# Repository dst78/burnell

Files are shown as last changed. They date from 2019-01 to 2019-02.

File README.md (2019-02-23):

# Burnell :: Clock and Clock Divider

## Abstract
This is a combined clock generator and clock divider module based on an Arduino Nano.

## Clock features
- Clock speed adjustable via potentiometer between 10 and 300 BPM.
- Gate length adjustable via potentiometer and gate / trigger toggle switch.
- Switches for start/stop and reset.
- Reset trigger output.
- Clock outputs for beat, bar, 8ths, 16ths and 32ths.

## Function of the gate length control
The gate length potentiometer varies the length of the high-state of an output between 5% and 95% of its interval.

This makes the module useful for both triggers and to control envelopes and similar modules which require long gates.

When the gate / trigger switch is in the trigger position then the high-state length of all outputs equals that of the 32ths output instead. You can still control the 32ths output gate length with the gate length potentiometer as before.

## Clock divider features
The clock divider section of the module has an external clock input so you can use it to divide an external pulse just as well as the internal clock. By default the clock divider is normalled to the bar output of the clock section.

The divider can be switched between three modes, which changes the outputs to:
- power of two: 2, 4, 8, 16, 32, 64, 128, 256
- primes      : 2, 3, 5, 7, 11, 13, 17,  19
- fibonacci   : 2, 3, 5, 8, 13, 21, 34,  55

The gate / trigger toggle switch of the clock section affects the gate length of the clock divider in the same way that it affects the clock outputs.

## Technical Specifications
The module is 12 HE wide.

Power consumption:
- 5V: 20mA
- +12V: 25mA
- -12V: 25mA

## Required Arduino Libraries
Burnell requires the following libraries:

- [PinChangeInterrupt](https://github.com/NicoHood/PinChangeInterrupt) by [Nico Hood](https://github.com/NicoHood) (version 1.2.6 confirmed to work) - also available directly through the library manager in the Arduino IDE
- [RBD_MicroTimer](https://github.com/dst78/arduinolib_RBD_MicroTimer) by [myself](https://github.com/dst78/) (version 1.4.1 confirmed to work).

**Do NOT use the RBD_Timer library found in the library manager**! It operates on milliseconds rather than microseconds and will not provide the resolution required for smooth clocks at higher BPM settings. Use my fork linked above instead and install it manually.

See the [Arduino Guide](https://www.arduino.cc/en/guide/libraries#toc5) on how to install a library manually if you're not sure how to do that.

## What's in the name
The module was named after [Jocelyn Bell Burnell](https://en.wikipedia.org/wiki/Jocelyn_Bell_Burnell), who together with Antony Hewish first discovered Pulsars when she was a postgraduate student. Antony Hewish, her supervisor, was awarded the Nobel price in Physics for the discovery. Burnell herself was omitted.

Pulsars are highly magnetized rotating neutron stars which emit beams of electromagnetic radiation. The beam can only observed when their beam is directed at earth. The so generated pulses are highly precise.

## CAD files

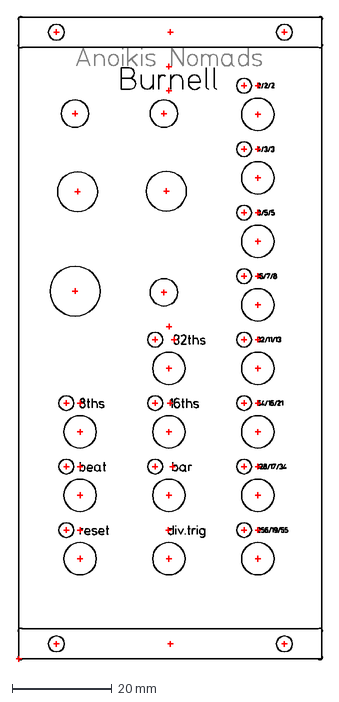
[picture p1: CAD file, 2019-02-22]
eurorack_panel/Burnell.dxf
61.4 x 129.1 mm

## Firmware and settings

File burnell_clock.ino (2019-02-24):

/**
 * Anoikis Nomads :: Burnell
 * Eurorack clock and clock divider module
 * 
 * All information on Burnell is on github: https://github.com/dst78/burnell
 * 
 * Released under Creative Commons Attribution-ShareAlike 3.0 Unported
 * https://creativecommons.org/licenses/by-sa/3.0/deed.de 
 * 
 * Pins and settings below are for an Arduino Nano.
 */
#include <PinChangeInterrupt.h>
#include <PinChangeInterruptBoards.h>
#include <PinChangeInterruptPins.h>
#include <PinChangeInterruptSettings.h>
#include <RBD_MicroTimer.h>

RBD::MicroTimer clockTimer;
RBD::MicroTimer divTimer;

//---- configure pins 
// input pins w/ interrupt
#define DIV_IN            2
#define RESET_IN          3
// digital output pins
#define SHIFTREG_SER      4
#define SHIFTREG_RCLK     5
#define SHIFTREG_SRCLK    6
#define RST_OUT           7
#define RST_LED           A4
// digital input pins
#define GATEMODE_IN       8
#define STARTSTOP_IN      9
// analog input pins
#define SPEED_IN         A2
#define GATELEN_IN       A1
#define DIVMODE_IN       A0


// program constants
#define DIVMODE_CLOCK     0
#define DIVMODE_POW       1
#define DIVMODE_PRIME     2
#define DIVMODE_FIBONACCI 3
#define GATEMODE_VARIABLE true
#define GATEMODE_FIXED    false
#define STARTED           true
#define STOPPED           false
// gate length range in percent
#define GATELEN_MIN       5
#define GATELEN_MAX      95
// clock speed and speed range in BPM
#define CLOCK_SPEED_MIN  10
#define CLOCK_SPEED_MAX 300
#define CLOCK_RESOLUTION 22.0

/**
 * raw array of divisions for clock and clock divider
 */
uint16_t divs[4][8] = {
  {1, 2, 4,  8, 16, 32,  64, 128}, // internal clock
  {2, 4, 8, 16, 32, 64, 128, 256}, // power of two
  {2, 3, 5,  7, 11, 13,  17,  19}, // prime numbers
  {2, 3, 5,  8, 13, 21,  34,  55}, // fibonacci sequence
};
/**
 * hiked up divisions, will be calculated dynamically based on CLOCK_RESOLUTION
 */
uint16_t subDivs[4][8] = {
  {0, 0, 0, 0, 0, 0, 0, 0},
  {0, 0, 0, 0, 0, 0, 0, 0},
  {0, 0, 0, 0, 0, 0, 0, 0},
  {0, 0, 0, 0, 0, 0, 0, 0}
};
/**
 * least common multiples for all steps in all division modes.
 * used to modulo the clock counters in a way that they never
 * overflow at a position where any of the digits skip a beat.
 */
uint32_t lcms[4] = {128, 256, 9699690, 2042040};

/**
 * interval length of the clock timer in microseconds
 */
double clkSpeed;

/**
 * current gatelength relative to CLOCK_RESOUTION / 100
 */
uint16_t gateLen;
/**
 * adjusted gatelength minimum / maximum in relation to CLOCK_RESOLUTION / 100
 */
uint8_t gateLenMin, gateLenMax;
/**
 * indicates the gate mode, derived from GATEMODE_IN
 */
volatile bool gateMode = GATEMODE_FIXED;
/**
 * whether the clock is started or stopped. derived from STARTSTOP_IN
 */
volatile bool started  = STOPPED;

/**
 * bit mask for the shift register. these are the clock outputs
 */
volatile uint8_t clockState;
/**
 * internal counter of the clock, counting CLOCK_RESOLUTION steps per 32ths
 */
volatile uint32_t clkResCount;

/**
 * indicates the clock divider mode. derived from the voltage at DIVMODE_IN.
 */
uint8_t divMode;

/**
 * bit mask for the shift register. these are the clock divider outputs
 */
volatile uint8_t divState;
/**
 * internal counter of the clock divider. counting CLOCK_RESOLUTION steps per divider input signal.
 */
volatile uint32_t divResCount;
/**
 * internal speed of the timer handling the clock divider, in microseconds.
 * derived from the time passing between HIGH signals on DIV_IN
 */
volatile double divClkSpeed;
/**
 * time keeping variables to calculate divClkSpeed
 */
volatile uint32_t divInterruptTime1, divInterruptTime2;

/**
 * analog pins are read in loop() only when this variable overflows.
 * this is required to save on CPU cycles and allow for fast BPM generation
 */
uint8_t loopCount;

void setup() {
  // correct array of clock substeps according to CLOCK_RESOLUTION
  correctClockResolution();
  
  // will be overridden in the first call of loop() so this initial value shouldn't ever be used
  divMode  = DIVMODE_POW; 

  // configure pins
  // interrupt pin
  pinMode(DIV_IN, INPUT);
  // digital output pins
  pinMode(SHIFTREG_SER, OUTPUT);
  pinMode(SHIFTREG_RCLK, OUTPUT);
  pinMode(SHIFTREG_SRCLK, OUTPUT);
  pinMode(RST_OUT, OUTPUT);
  pinMode(RST_LED, OUTPUT);
  // analog input pins
  pinMode(SPEED_IN, INPUT);
  pinMode(GATELEN_IN, INPUT);
  pinMode(DIVMODE_IN, INPUT);

  // read startup values
  if (digitalRead(STARTSTOP_IN) == HIGH) {started = STARTED;}
  if (digitalRead(GATEMODE_IN) == HIGH) {gateMode = GATEMODE_VARIABLE;}
  
  // set up pin change interrupts
  attachPCINT(digitalPinToPCINT(GATEMODE_IN), handleGateModeChange, CHANGE);
  attachPCINT(digitalPinToPCINT(STARTSTOP_IN), handleStartStop, CHANGE);
  attachPCINT(digitalPinToPCINT(RESET_IN), reset, CHANGE);

  /**
   * 1 beat is giving BPM
   * we're outputting up to resolution of 32ths, which is 1/8ths of 1 beat
   * 
   * with adjustable gatelengths we need to be precise to CLOCK_RESOLUTION-th of 1/32ths.
   */
  clkSpeed    = (1000000.0 / CLOCK_RESOLUTION) / (map(389, 0, 1023, CLOCK_SPEED_MIN, CLOCK_SPEED_MAX) / 7.5); // 120 BPM in 3200ths resolution
  gateLen     = map(512, 0, 1023, gateLenMin, gateLenMax); // 50% initial gate length
  clockTimer.setTimeout(clkSpeed);

  divClkSpeed = 0;
  divTimer.setTimeout(divClkSpeed);
  divTimer.stop();

  // attach interrupt to clock division input
  attachInterrupt(digitalPinToInterrupt(DIV_IN), handleDivClockTrigger, RISING);
  // initialize clocks & update registers
  initClocks();

  // initialize loopCount
  loopCount = 0;
}

void loop() {
  double rawSpeed, bpm, clockUs;

  // loopCount is used to read values only every so often in order to increase the maximum BPM
  if (loopCount == 0) {
    // determine clock divider mode
    uint16_t divModeVoltage = analogRead(DIVMODE_IN);
  
    if (divModeVoltage < 102) {
      divMode = DIVMODE_PRIME;
    } else if (divModeVoltage < 491) {
      divMode = DIVMODE_FIBONACCI;
    } else {
      divMode = DIVMODE_POW;
    }
  }

  if (loopCount == 85) {
    // read relative gate length
    gateLen   = map(analogRead(GATELEN_IN), 0, 1023, gateLenMin, gateLenMax);
  }

  if (loopCount == 170) {
    // read raw clock speed and calculate interrupts
    rawSpeed  = analogRead(SPEED_IN);
    bpm       = map(rawSpeed, 0, 1023, CLOCK_SPEED_MIN, CLOCK_SPEED_MAX);
    // resolution in 1,000,000ths of a second (1 microsecond) divided by clock resolution
    // 7.5 is 1/8ths of 60, which gives us 1/32ths resolution
    clockUs = (1000000.0 / CLOCK_RESOLUTION) / (bpm / 7.5);
    
    if (clockUs != clkSpeed) {
      clkSpeed = clockUs;
      clockTimer.setTimeout(clkSpeed);
    }
  }

  // advance clocks
  if (started) {
    if (clockTimer.onRestart()) {
      advanceClock();
    }
    if (divTimer.onRestart()) {
      advanceDivClock();
    }
  }  
  
  loopCount++;
}

/**
 * initializes the timers and registers
 */
void initClocks() {
  clockState     = 0x00;
  divState       = 0x00;  
  clkResCount    = 1;
  divResCount    = 1;
  
  writeRegisters(clockState, divState);
}

/**
 * resets all counters
 * 
 * doubles as pin change interrupt handler
 */
void reset() {
  uint8_t trigger = getPinChangeInterruptTrigger(digitalPinToPCINT(RESET_IN));

  if (trigger == FALLING) {
    clockTimer.stop();
    divTimer.stop();
    
    initClocks();
    started = STOPPED;
  
    digitalWrite(RST_OUT, HIGH);
    digitalWrite(RST_LED, HIGH);
    
  } else if (trigger == RISING) {
    clockTimer.restart();
    divTimer.restart();

    started = STARTED;
    
    digitalWrite(RST_OUT, LOW);
    digitalWrite(RST_LED, LOW);
  }
}

/**
 * writes to the 74595 chips
 */
void writeRegisters(uint8_t clk, int8_t divi) {
  digitalWrite(SHIFTREG_RCLK, LOW);
  shiftOut(SHIFTREG_SER, SHIFTREG_SRCLK, LSBFIRST, clk);
  shiftOut(SHIFTREG_SER, SHIFTREG_SRCLK, LSBFIRST, divi);
  digitalWrite(SHIFTREG_RCLK, HIGH);  
}

/**
 * manipulates a bit of the clock mask in a generic way
 *
 * @param uint8_t  mask              mask to manipulate
 * @param uint16_t ticks             current clock ticks
 * @param uint16_t ticksThreshold    threshold when the current bit should go high
 * @param uint16_t hiLen             how many ticks the current bit should remain high
 * @param uint16_t hiLenMult         multiplicator for the hiLen value
 * @param uint8_t bit                which bit to manipulate
 * @return uint8_t                   the manipulate clock mask
 */
int setRegisterBits(uint8_t mask, uint16_t ticks, uint16_t ticksThreshold, uint16_t hiLen, uint16_t hiLenMult, uint8_t bitv) {
  if (gateMode == GATEMODE_VARIABLE) {
    if (ticks % ticksThreshold >= hiLen * hiLenMult) {
      // set low
      mask &= ~(1 << bitv);
    } else if (ticks % ticksThreshold == 0) {
      // set high
      mask |= (1 << bitv);
    }
    
  } else {
    // fixed gateMode
    if (ticks % ticksThreshold >= hiLen) {
      // set low
      mask &= ~(1 << bitv);
    } else if (ticks % ticksThreshold == 0) {
      // set high
      mask |= (1 << bitv);
    }
  }

  return mask;
}

/**
 * advances the internal clock
 */
void advanceClock() {
  // set relevant clock bits hi/lo according to our metric
  clockState = setRegisterBits(clockState, clkResCount, subDivs[DIVMODE_CLOCK][0], gateLen, divs[DIVMODE_CLOCK][0], 0);
  clockState = setRegisterBits(clockState, clkResCount, subDivs[DIVMODE_CLOCK][1], gateLen, divs[DIVMODE_CLOCK][1], 1);
  clockState = setRegisterBits(clockState, clkResCount, subDivs[DIVMODE_CLOCK][2], gateLen, divs[DIVMODE_CLOCK][2], 2);
  clockState = setRegisterBits(clockState, clkResCount, subDivs[DIVMODE_CLOCK][3], gateLen, divs[DIVMODE_CLOCK][3], 3);
  clockState = setRegisterBits(clockState, clkResCount, subDivs[DIVMODE_CLOCK][5], gateLen, divs[DIVMODE_CLOCK][5], 5);
  
  writeRegisters(clockState, divState);
  
  // modulo operation on clkResCount to prevent overflow at fractions of CLOCK_RESOLUTION
  clkResCount = (clkResCount + 1) % lcms[DIVMODE_CLOCK];
}

/**
 * advances the clock divider, called by TimerOne
 */
void advanceDivClock() {
  divState = setRegisterBits(divState, divResCount, subDivs[divMode][0], gateLen, divs[divMode][0], 0);
  divState = setRegisterBits(divState, divResCount, subDivs[divMode][1], gateLen, divs[divMode][1], 1);
  divState = setRegisterBits(divState, divResCount, subDivs[divMode][2], gateLen, divs[divMode][2], 2);
  divState = setRegisterBits(divState, divResCount, subDivs[divMode][3], gateLen, divs[divMode][3], 3);
  divState = setRegisterBits(divState, divResCount, subDivs[divMode][4], gateLen, divs[divMode][4], 4);
  divState = setRegisterBits(divState, divResCount, subDivs[divMode][5], gateLen, divs[divMode][5], 5);
  divState = setRegisterBits(divState, divResCount, subDivs[divMode][6], gateLen, divs[divMode][6], 6);
  divState = setRegisterBits(divState, divResCount, subDivs[divMode][7], gateLen, divs[divMode][7], 7);

  writeRegisters(clockState, divState);
  
  // modulo operation on clkResCount to prevent overflow at fractions of CLOCK_RESOLUTION
  divResCount = (divResCount + 1) % lcms[divMode];
}

/**
 * interrupt handler when a rising signal on the clock division pin was detected.
 */
void handleDivClockTrigger() {
  uint32_t now = micros();
  uint8_t remainder = (divResCount % (uint8_t) CLOCK_RESOLUTION);

  // calculate new clock speed
  divInterruptTime1 = divInterruptTime2;
  divInterruptTime2 = now;
  divClkSpeed = (divInterruptTime2 - divInterruptTime1) / CLOCK_RESOLUTION;

  // update the timer
  divTimer.setTimeout(divClkSpeed);
  divTimer.restart();

  // correct the divisor count to a multiple of CLOCK_RESOLUTION to stay in sync with triggers
  if (remainder > 0) {
    divResCount += CLOCK_RESOLUTION - remainder;
  }
}

/**
 * pin change interrupt handler
 */
void handleGateModeChange() {
  uint8_t trigger = getPinChangeInterruptTrigger(digitalPinToPCINT(GATEMODE_IN));

  if (trigger == RISING) {
    gateMode = GATEMODE_VARIABLE;
  } else if (trigger == FALLING) {
    gateMode = GATEMODE_FIXED;
  }
}

/**
 * pin change interrupt handler
 */
void handleStartStop() {
  // Differenciate between RISING and FALLING on mode CHANGE.
  uint8_t trigger = getPinChangeInterruptTrigger(digitalPinToPCINT(STARTSTOP_IN));
  
  if (trigger == RISING) {
    started = STARTED;
  } else if (trigger == FALLING) {
    started = STOPPED;
    writeRegisters(0x00, 0x00); // pull all outputs low
  } 
}

/**
 * corrects the substep count in subDivs array according to CLOCK_RESOLUTION.
 * will also recalculate gate length range 
 */
void correctClockResolution() {
  for (uint8_t i = 0; i < 4; i++) {
    for (uint8_t j = 0; j < 8; j++) {
      subDivs[i][j] = divs[i][j] * CLOCK_RESOLUTION;
    }

    lcms[i] = lcms[i] * CLOCK_RESOLUTION;
  }

  // map gatelengths relative to CLOCK_RESOLUTION as well
  gateLenMin = (GATELEN_MIN * CLOCK_RESOLUTION) / 100;
  gateLenMax = (GATELEN_MAX * CLOCK_RESOLUTION) / 100;
}

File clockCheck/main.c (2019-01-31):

#include <stdio.h>
#include <stdlib.h>
#include <unistd.h>
#include <math.h>

/**
 * This routine verifies the clock generation algorithm with custom
 * gate lengths.
 */
const int GATELEN_MIN = 5;
const int GATELEN_MAX = 95;
const int ITERATIONS = 6400;

int iterations;
int gateLen;
int clockState;
int progress;

void reset() {
  clockState = 0x00;
  progress   = 0;
}

void printBinary(int n) {
  for (int i = 7; i >= 0; i--) {
    if (n & (1 << i)) {
      printf("1");
    } else {
      printf("0");
    }
  }
}

/**
 * manipulates a bit of the clock mask in a generic way
 *
 * @param uint8_t  mask              mask to manipulate
 * @param uint16_t ticks             current clock ticks
 * @param uint16_t ticksThreshold    threshold when the current bit should go high
 * @param uint16_t hiLen             how many ticks the current bit should remain high
 * @param uint8_t bit                which bit to manipulate
 * @return uint8_t                   the manipulate clock mask
 */
int setRegisterBits(int mask, int ticks, int ticksThreshold, int hiLen, int bit) {

  if (ticks % ticksThreshold == hiLen) {
    // set low
    mask &= ~(1 << bit);

  } else if (ticks % ticksThreshold == 0) {
    // set high
    mask |= (1 << bit);
  }

  return mask;
}

void writeRegister(int prog, int clock) {
  static int oldData = 0;

  //if (oldData != clock) {
  if (oldData != clock) {
    printf("%06d  ", prog);
    printBinary(clock);
    printf("\n");

    oldData = clock;
  }
}

void advanceClock() {
  progress++;

  if (progress % 100 == 0) {clockState++;;}

  // set relevant clock bits hi/lo according to our metric
  clockState = setRegisterBits(clockState, progress, 100, gateLen, 0);
  clockState = setRegisterBits(clockState, progress, 200, gateLen * 2, 1);
  clockState = setRegisterBits(clockState, progress, 400, gateLen * 4, 2);
  clockState = setRegisterBits(clockState, progress, 800, gateLen * 8, 3);
  clockState = setRegisterBits(clockState, progress, 3200, gateLen * 32, 5);

  writeRegister(progress, clockState);
}

int main(int argc, char *argv[]) {
  int opt;
  gateLen    = GATELEN_MIN;
  iterations = ITERATIONS;

  // parse command line arguments
  while((opt = getopt(argc, argv, "l:i:")) != -1) {
    switch(opt) {
      case 'l':
        gateLen = (int) fmin(GATELEN_MAX, fmax(GATELEN_MIN, atoi(optarg)));
        break;
      case 'i':
        iterations = (int) fmax(0, atoi(optarg));
        break;
      case ':':
        printf("option needs a value\n");
        return 1;
        break;
      case '?':
        printf("unknown option: %c\n", optopt);
        return 1;
        break;
    }
  }

  reset();

  printf("testing clock progression\n");
  printf("gate length: %d/100\n", gateLen);
  printf("iterations : %d\n", iterations);
  printf("ticks not printed means no change in clock signal\n\n");

  printf("ticks   clock   \n");
  printf("----------------\n");

  for (int c = 0; c < iterations; c++) {
    advanceClock();
  }
}

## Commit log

2019-01-31 interims checkin
    [dump.txt]
2019-02-03 implemented interrupts for start/stop, reset and gateMode change
    [burnell_clock.ino]
2019-02-04 changed the power-of-two sequence again
2019-02-10 Rev A of the circuit done, QA still pending
2019-02-10 minor circuit correction
2019-02-22 working circuit and Arduino code
2019-02-22 added panel and silkscreen
    [Burnell.dxf]
2019-02-22 added separate pin for reset LED
2019-02-23 changed the reset button pin change interrupt to CHANGE, in order to get rid of delay() calls
2019-02-23 listing required Arduino libraries
2019-02-23 fixed fluctuating voltages to cause missing steps
    [burnell_clock.ino]
2019-02-24 ahem, ... 16 is not a prime number. silkscreen corrected
2019-02-24 wrapping internal counters at least common multiple in order to prevent any of the outputs to skip a beat when the counter overflows / wraps
    [burnell_clock.ino]
2019-02-24 corrected internal counter value at reset() so that outputs are all LOW when button is released
    [burnell_clock.ino]
